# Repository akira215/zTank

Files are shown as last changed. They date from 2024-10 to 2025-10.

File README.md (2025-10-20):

# zTank
Tank survey, embedded sofware on dedicated PCB using ESP32C6 µC

# Description

This repository contain all the development for an electronic device that will monitor a water tank (such as rain collect tank) using zigbee to transmit data to a coordinator. It contains: 
 * A PCB design [PCB design](PCB/README.md)
 * An enclosure design to be printed in 3D [Enclosure design](3Dprint/README.md)
 * Source code of the embedded software on the board (in an ESP32C6 µC)
 * An External converter for Zigbee2MQTT service [external converter](external_converters)

# Principle

The board will collect data from various sensors surch as:
 * Upstream static pressure (pump side)
 * Downstream static pressure (home side) - difference between upstream and downstream static pressure is used to estimate filters clogging
 * Water level sensor, to estimate the available water volume in the tank
 * water pulse meter to count the consumption in the home
 * Additionally on board temperature sensor could be monitor

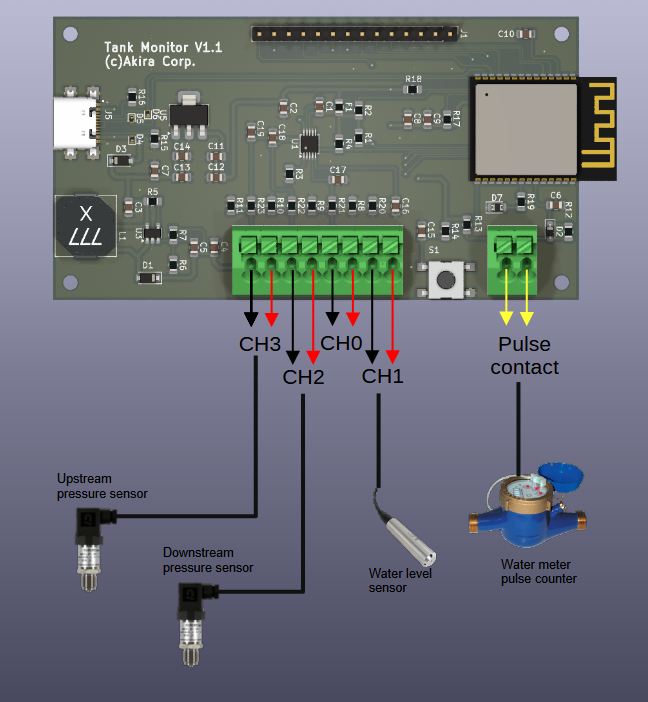
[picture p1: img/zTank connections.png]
zTank connections
 

 The 3 first sensors shall be 4-20mA sensor directly connected to the board. The water counter shall be a dry contact meter, connected to the board

 All these sensors have a calibration factor that can be updated directly form Zigbee2MQTT GUI. To avoid losing calibration, the device itself will keep updated theses factor in its Non Volatile Storage.

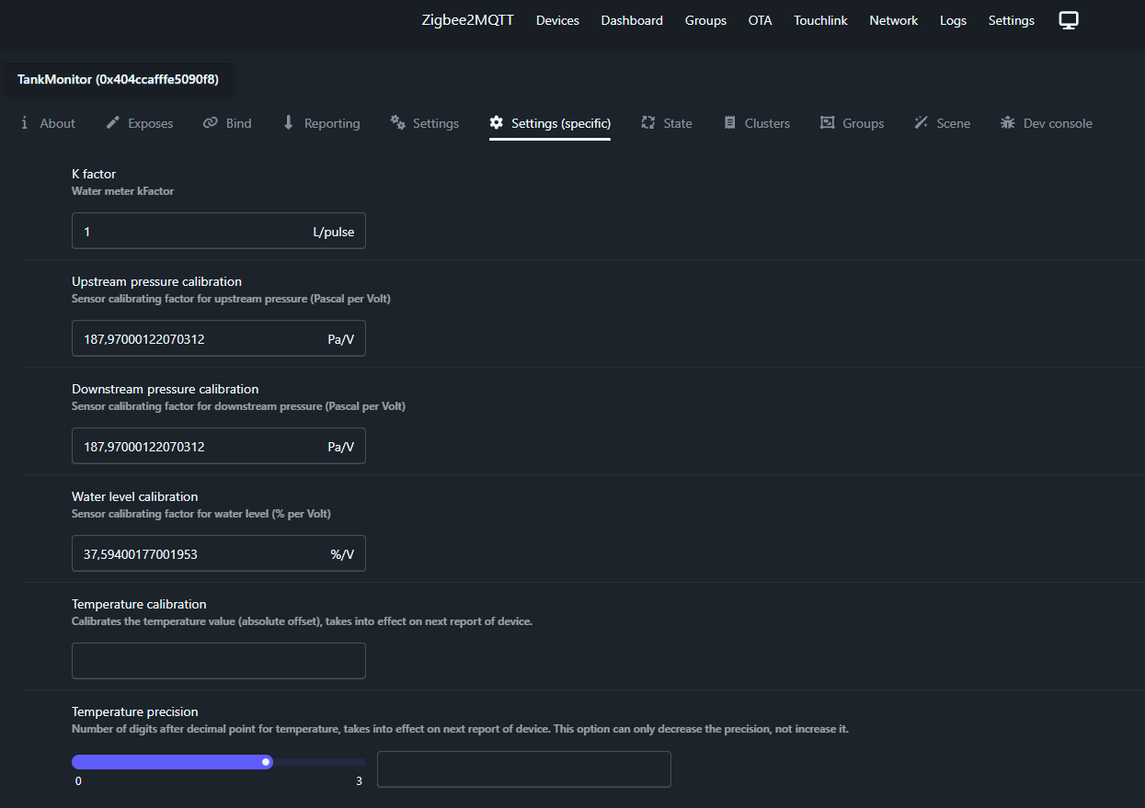
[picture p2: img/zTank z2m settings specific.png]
z2m settings (specific)


A 4-20mA input is available for any other futher sensor requirement. Adding a sensor will require to :
 * Update the embedded software
 * Update the external converter on Zigbee2MQTT side

## Usage

  * Short press button to join the zigbee network (coordinator shall grant pairing) -> LED shall flash, until network is joined, it then shutoff
  * Long press button to leave network. When the LED is fixed on, the device is not connected to the network neither is trying to join

## Sensor selection

### Upstream and downstream static pressure

  Regular pressure transmitter are not so expensive and efficient for that purpose. These 2 sensors shall have a measured range according to installation pressure. In regular network, pressure is limited to 3 bars, so selecting a sensor 0-5 bars seems a good choice. If the upper value is higher, the resolution of the measurement will be less as the ADC converter resolution is fixed.

  The shunt to convert current to tension for the ADC converter is 133R, and Imax for the sensor @max range will be 20mA so Umax for ADS1115 will be 2.66V (U=R*I). 5 bars = 500 kPa, so the calibration factor shall be 500 kPa / 2.66V = 187.97 kPa/V. Of course this factor shall be adjusted by measuring at the same location of one sensor the pressure, and correcting the reading of the sensor, but this short computation can help to start setting up calibration factor

### Water level

  Whatever technology of sensor could be used as soon as its output is 4-20mA current. Tests have been done using submerged differential pressure sensor, with the balance pipe to get the atmospheric pressure that run with the electrical cable, they worked properly. The range of this sensor shall be in accordance with the depth of the tank. The output value of Zigbee2MQTT will be a % of depth (meaning 100% when tank is full). Depending on the shape and cross section of the tank, this could be converted to a volume directly in the Z2M external converter, or outside Z2M in another software.

  The shunt to convert current to tension for the ADC converter is 133R, and Imax for the sensor @max range will be 20mA so Umax for ADS1115 will be 2.66V (U=R*I). For 100% the calibration factor shall be 100% / 2.66V = 37.594 %/V. 
  
  Of course this factor shall be adjusted when tank is full to read 100% in the Zigbee2MQTT output. For example, if yo have a 0-2m sensor and the require stroke of your tank (max height - min height before depriming pump) is 1.5m, it means that the 100% value of your tank will occur when sensor will read 1.5m (take care to install the sensor just before depriming pump). The voltage at the converter will be 1.5m/2m * 2.66V = 1.995V, so you will have to set the calibration factor considering 100% / 1.995V = 50.125%/V

### Water pulse counter

  The water meter shall send a pulse each XX L, whatever XX is. It is expected to have a dry contact that switch on and off each pulse. Hardware debouncer has been implemented for a particular counter, measuring bouncing using an oscilloscope. Computation of this RC filter has been provided here:
  [Spreadsheet](<PCB/2024-06-29 Comput.ods>)
    
  The kFactor to be set up in Zigbee2MQTT is only the L per pulse of the counter.

## Zigbee2MQTT integration

### External converter

External converter shall be loaded according to Zigbee2MQTT instructions:

[Zigbee2MQTT external converters](https://www.zigbee2mqtt.io/advanced/more/external_converters.html)

Restart Zigbee2MQTT `Webpage > Settings > Tools > Restart Zigbee2MQTT`

### Pairing zTank device

If the LED is fixed on, short press one time on the button, this will put the device in pairing mode.
Device is in Pairing Mode when the LED flahes quickly. 

Put Coordinator (or other device) in pairing mode using Zigbee2MQTT GUI (antenna symbol on the upper right of the screen with mention `All`)

After a short time, LED shall stop flashing. When LED is off, device is paired. You can check on Zigbee2MQTT device list

### Device icon

To add an icon in Zigbee2MQTT GUI, create a folder named `device_icon` in the root of Zigbee2MQTT docker installation (folder containing `configuration.yml`). In that foler, put the `zTank_icon.png` file contained in the `img` directory of this repository.

On Zigbee2MQTT GUI, go to `Devices` list and click on the device. Go to `Settings` tab and scroll down to the `icon` box.
Put `device_icons/zTank_icon.png` in that box. Icon shall be visible on Zigbee2MQTT GUI.

### Reporting

To develop*******************************************************************

## Build Instructions

The embedded software required `esp-ash-components`:

```
git submodule add https://github.com/akira215/esp-ash-components.git components
```

Create a partition.csv for zigbee and configure menuconfig with custom partition table (shall be done by default)

## Configuration

Configuration is available in `menuconfig` in the `Project setting` section:

### Pin Layout

  This section refer to hardware connection of LED button and volume meter. <span style="color:red">**These settings shall not be changed unless new hardware is developped.**</span>

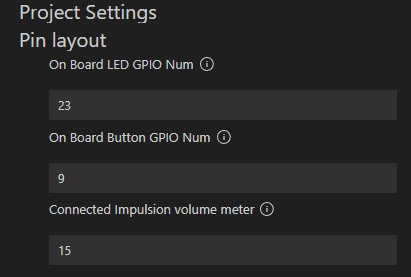
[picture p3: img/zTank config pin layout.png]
pin layout


### Zigbee endpoints

  This section refer to the endpoint for each sensor of the device. Any change in this number require to update the external converter accordingly

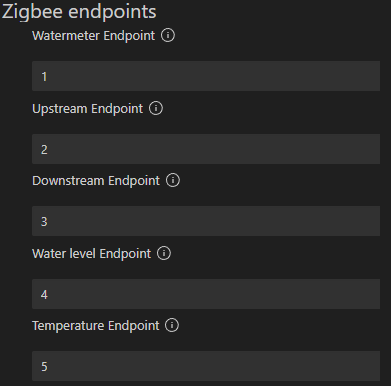
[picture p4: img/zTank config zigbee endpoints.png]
Zigbee endpoints


  And in Zigbee2MQTT external converter:

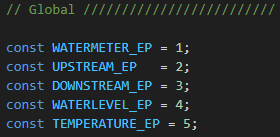
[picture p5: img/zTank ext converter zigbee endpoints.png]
External converter


### Zigbee device

  Zigbee stack has been sized doing extensive tests. <span style="color:red">**This setting shall not be changed.**</span>

Zigbee device

### ADS Pin Layout

  This section refer to hardware connection of ADS1115 converter to µC pin. <span style="color:red">**These settings shall not be changed unless new hardware is developped.**</span>

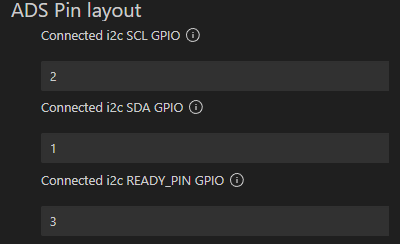
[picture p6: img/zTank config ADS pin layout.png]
ADS pin layout


### ADS Converter config

  The first 3 inputs refer to the channel in which each sensor is connected. Take care that channel are not implemented on the connector in a logical order, so please refer to pictures that describe which pins of the connector is connected to which ADC channel (and polarity for sensors)

  The delay between 2 queries of ADS is the update rate of the measurement. Between 2 measurement, ADS is put in sleep to optimize consumption. Take care that driver will trigger one conversion for each channel, so there is a minimal time between 2 queries, depending on the resolution set for the ADS.

  The delay between 2 queries of temperature is the update rate of the measurement of the internal µC temperature sensor.

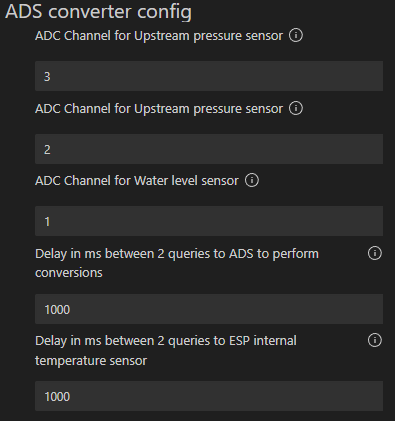
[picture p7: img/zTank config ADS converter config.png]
ADS converter config


## Current Status

Still work in progress, but is completely running. All bugs 
could be reported to try to improve it.

## PCB design

[PCB design](PCB/README.md)

## Enclosure design design

[Enclosure design](3Dprint/README.md)

## Caveats

### To be developped

OTA update

## Usage and Examples

## Changes

### New in version 0.0.0

## Credits

 * [Zigbee2MQTT](https://github.com/Koenkk/zigbee2mqtt)

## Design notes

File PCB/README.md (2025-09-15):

# zTank PCB
A dedicated PCB using ESP32C6 µC as been designed to optimize reliability and costs.

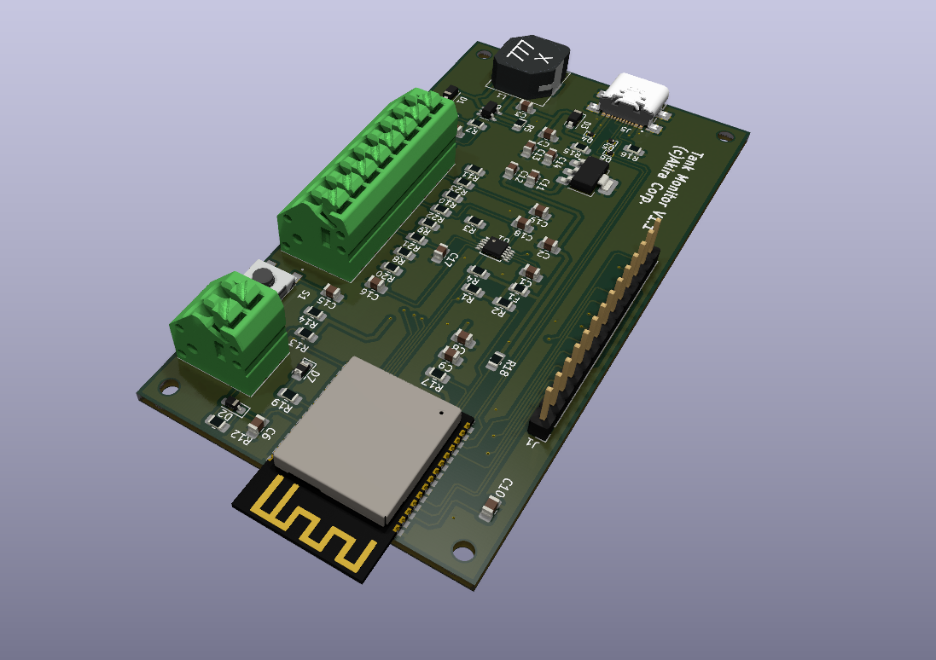
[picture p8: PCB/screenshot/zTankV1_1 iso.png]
Iso view of zTank PCB


## Tools

 The design of the PCB has been done with KiCad 9.0. Particular footprint and 3D STEP file are included in the `/footprints` folder for sake of maintenance

## Design

 The design is based on ESP32C6 WROOM with the following peripherials:
 * USB for power, flash device and output serial debug / info.
 * Powering circuit is done using MCP1826S 
 * A 4-20mA loop is built based on a LM2735X (1.6MHz) to raise voltage to about 20V
 * 4 channels 4-20mA sensors is provided and converted using ADS1115IDGS. It communicate with µC with i2c port
 * a debounced contact is provided for pulse counter
 * A push button is also provided for very simple HMI
 * PCB is also equipped by a LED for simpl HMI
 * Finally PCB is equipped with header that can be used for a touchscreen device in case of future needs (software lib already written and tested)

 Component size has been selected to 0805, except ESD protective diodes that are smaller.

### USB

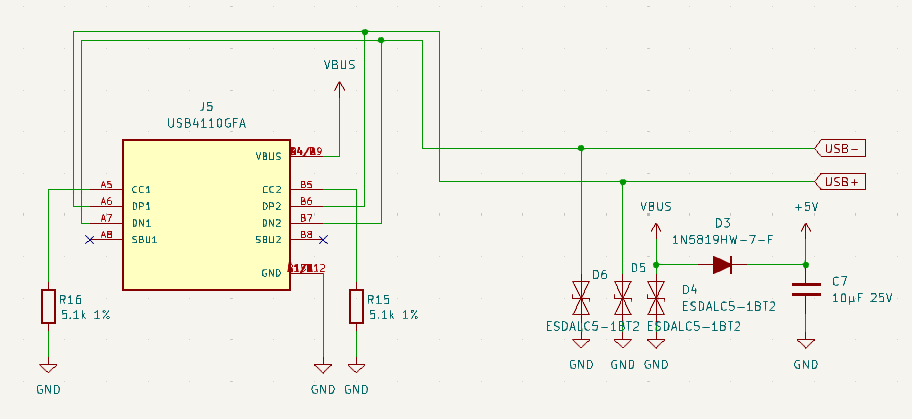
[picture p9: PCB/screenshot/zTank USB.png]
USB schematic
  

  USB socket is grounded to the main ground planes (2 sides).
  USB Lines `USB-` and `USB+` are directly connected to ESP32C6 to flash and monitor µC.
  `VBUS` is used to provide `+5V` (which is in fact lower than +5V) via a protective diode `D3`.

  All this 3 lines are protected by ESD protective diode.

### Voltage regulator

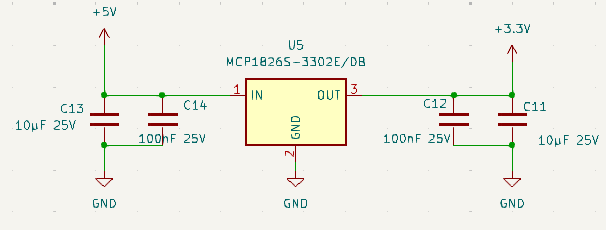
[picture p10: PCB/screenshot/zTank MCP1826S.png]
Regulator schematic
  

  All the board is powered using `+3.3V`. This voltage is provided by a fixed low-voltage regulator MCP1826S-3302E that can provide up to 1000mA.
  Fixed voltage regulator requires only few external component, in this case only capacitors are installed as per datasheet.

### 4-20mA Voltage circuit

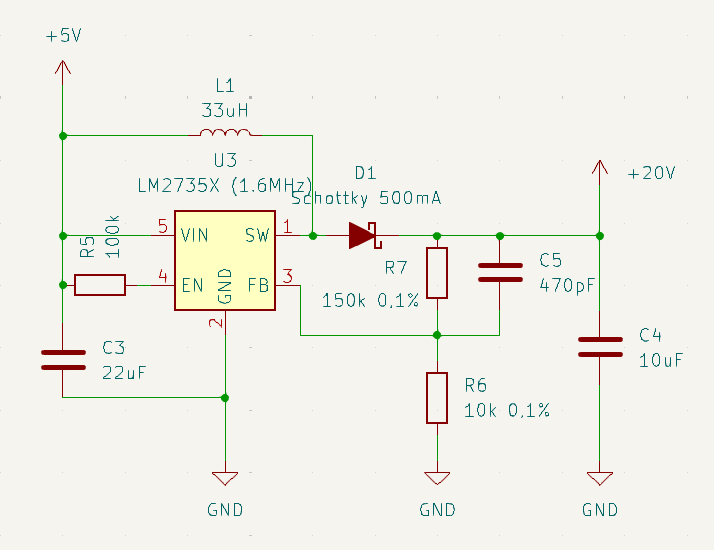
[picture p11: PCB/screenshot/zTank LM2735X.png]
LM2735X schematic
  

  To avoid noise on lines and due to voltage drop at each stage, 4-20mA loop voltage shall be at around 20V. Care shall be taken when changing this voltage as it may require adjustment (in the shunt values for instance) to avoid damaging other components.

  This voltage is produced from `+5V` using a boost type regulator LM2735X (@1.6MHz). Computation of the external components are provided in the LibreOffice Spreadsheet [PCB comput spreadsheet](<2024-06-29 Comput.ods>). A 33µH inductance has been selected to get a clean output voltage to avoid noise on sensors line.

### 4-20mA conversion

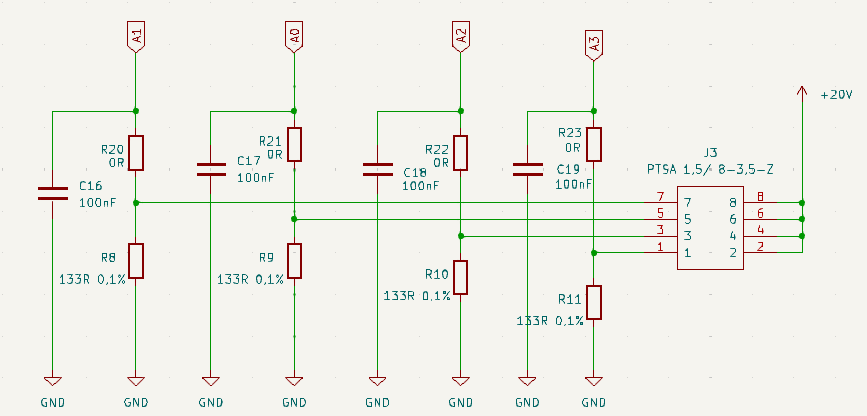
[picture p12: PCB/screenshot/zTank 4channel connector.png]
4 channel connector schematic
 

  4 channels are available via Phoenix contact 8 poles connector. Each channel input current is injected in a 133R shunt (low tolerance resistor) to output a voltage below 3.3V. A 100nF capacitor is provided to reduce noise.

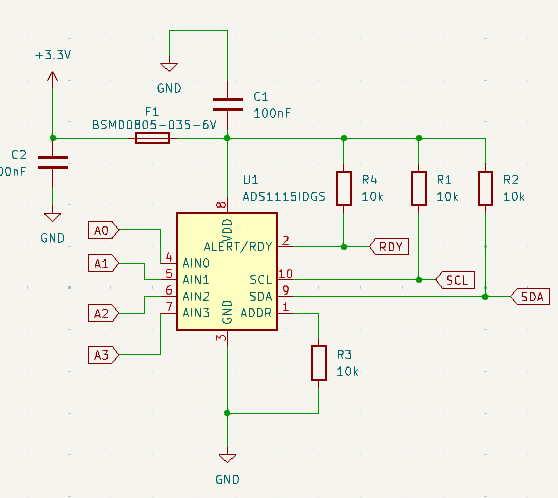
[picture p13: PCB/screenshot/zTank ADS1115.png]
ADS1115 schematic
  

  Each channel voltage is then converted in a digital signal using an ADS1115IDGS, that communicate with µC using i2c protocol. A ready pin is used to trigger an interrupt to the µC when data are available.
  External components are:
   * 10k resistor connected to the ground for the address of the device (only one on board so gnd is the common one)
   * 10k pull-up resistor on each signal (`SCL`, `SDA`, `RDY`) connected to µC
   * Decoupling capacitor for power lines and rearmable fuse to protect circuit

### Debounced contact

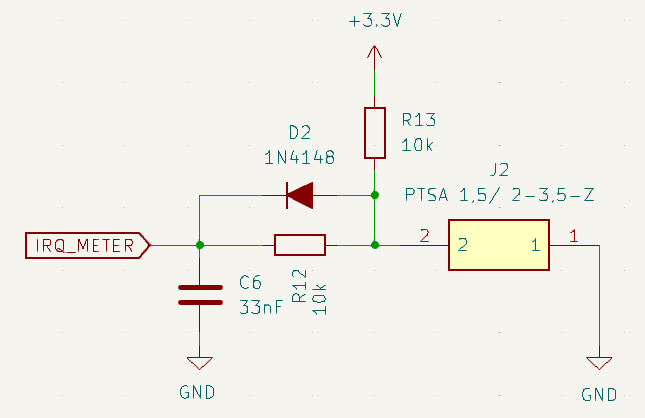
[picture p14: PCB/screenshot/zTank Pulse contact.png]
Debounced pulse schematic


An harware RC filter has been set up on this input to avoid false triggering. The computation of this filter is detailed in the spreadsheet file [PCB comput spreadsheet](<2024-06-29 Comput.ods>), bouncing duration has been measured using an oscilloscope in a unique water meter equiped with dry contact pulse output. It may be required to adjust this filter if the water meter seems to input false pulse to the µC. 

The only other component is a pull-up resistor to not let a float input.

### µC ESP32C6 WROOM

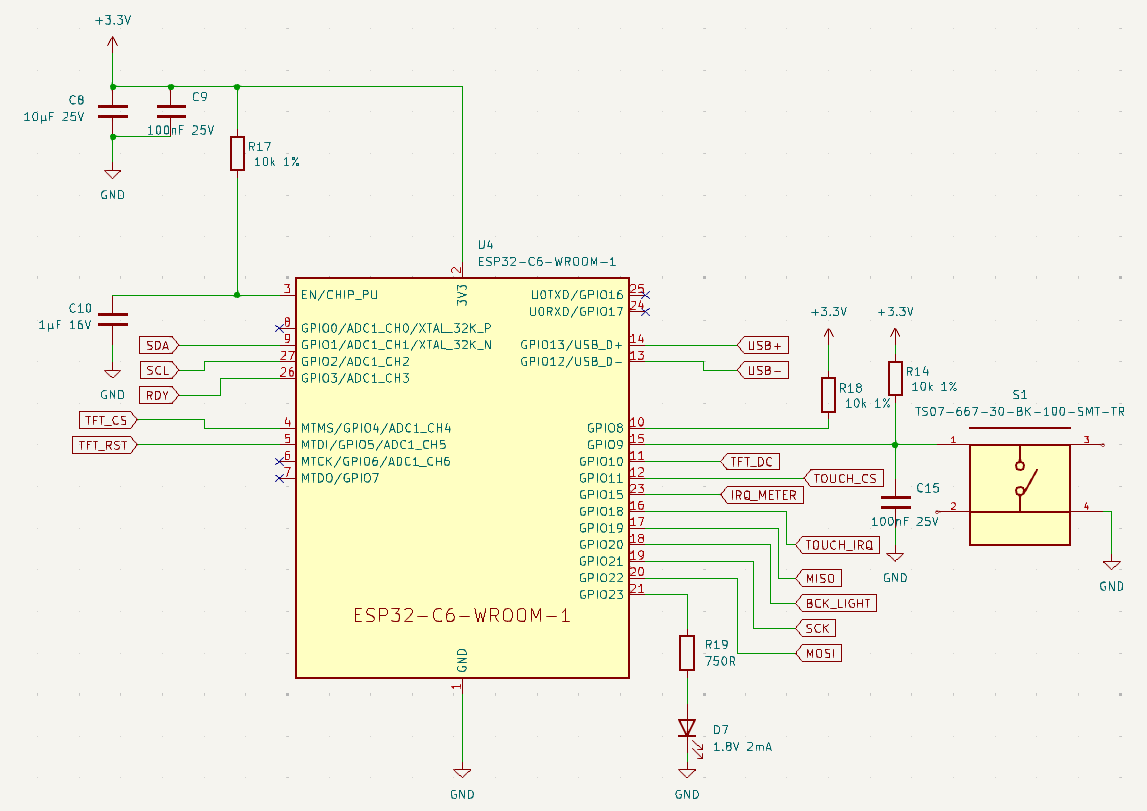
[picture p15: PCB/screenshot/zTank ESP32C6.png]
µC schematic


ESP32C6 power up is done using decoupling capacitor (10µF // 100nF).

The `EN` pin is driven to the `+3.3V` to enable the µC. 

`GPIO9` shall be pulled up to `+3.3V` to set the µC in normal execution mode (instead of ROM serial bootloader when `GPIO9` is pulled to the ground). Despite the doc says that it has an internal pull-up, µC will not boot normally after reporg if not driven to `+3.3V`.

`GPIO8` shall be driven to `+3.3V` as doc says, in order to enter the serial bootloader reliably.

### Push Button

Push button has been connected to `GPIO9`, so it can be used to boot/flash device by driving the pin low. Indeed, no operation is required on this button to flash µC using USB directly, and push button is used by software for HMI purpose.

### Led

A led is connected to `GPIO23` for HMI purpose as well. Resistor has been calculated according to LED spec to grant the required current.

### Header

A header is available to drive a touchscreen if required. It has not been integrated in the enclosure of this repo. It was planned and tested using a ILI9341 TFT touchscreen.

## PCB fabrication

Gerber files are included for fabrication. A batch of PCB has been produced by JLCPCB with the following configuration:

|Base Material |	FR-4	 | Layers |	2 |
|---|---|---|---|
|Dimension |	49 mm* 91 mm | PCB Qty |	20 |
|Product Type |	Industrial/Consumer electronics | Different Design |	1 |
|Delivery Format |	Single PCB	 | PCB Thickness |	1.6mm |
|Specify Stackup |	no	 | Layer Sequence | |	
|PCB Color |	Purple	 | Silkscreen |	White |
|Material Type |	TG135	 | Via Covering |	Tented |
|Surface Finish |	ENIG Gold Thickness: 1U"	 | Deburring/Edge rounding |	No |
|Outer Copper Weight  |	1 oz	 | Gold Fingers |	No |
|Electrical Test |	Flying Probe Fully Test	 | Castellated Holes |	no |
|Edge Plating |	No	 | Mark on PCB	 | Order Number |
|Blind Slot |	No	 | Min via hole size/diameter |	0.3mm/(0.4/0.45mm)|
|4-Wire Kelvin Test |	No	 | Paper between PCBs |	No |
|Appearance Quality |	IPC Class 2 Standard	 | Confirm Production file |	No |
|Silkscreen Technology|	Ink-jet/Screen Printing Silkscreen | Package Box |	With JLCPCB logo  |
|Inspection Report |	No	 | Board Outline Tolerance |	±0.2mm(Regular) |
|UL Marking |	No	 | Countersink Hole |	No |

## Assembly

A stencil as been produced by JLCPCB, so the assembly has been done using solder paste, manually placing components, and reflow is done using an hot plate.

The components that generate issues during that process are:
 * USB connector `J5` : often some bridges are created due to the high density of pin. It has to be manually fixed
 * ESD protection diodes `D4`, `D5` & `D6`: are they are really small and light, they moved during the reflow process. It has to be manually fixed with a soldering iron, as hot air gun make them move anyway whaterver the airflow is
 * Care should be taken on the pin of ADS converter `U1`(bridges) and µC `U4` (alke of solder)
 * Obviously connector `J1`, `J2` and `J3` have to be solded manually

## Usage

For routing simplicity, 4-20mA channels are not reparted logically on the board, please consider the scheme here below.

Debounced pulse contact don't have polarity.

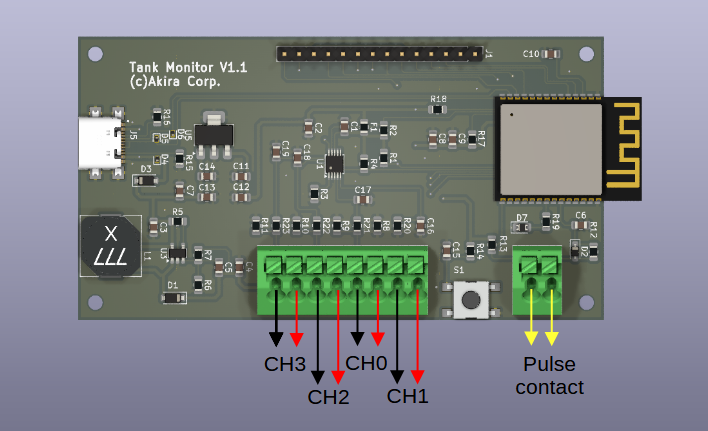
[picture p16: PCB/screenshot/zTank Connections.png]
Board connectors


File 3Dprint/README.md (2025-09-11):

# zTank Enclosure
The enclosure has been designed to fit and support the PCB.

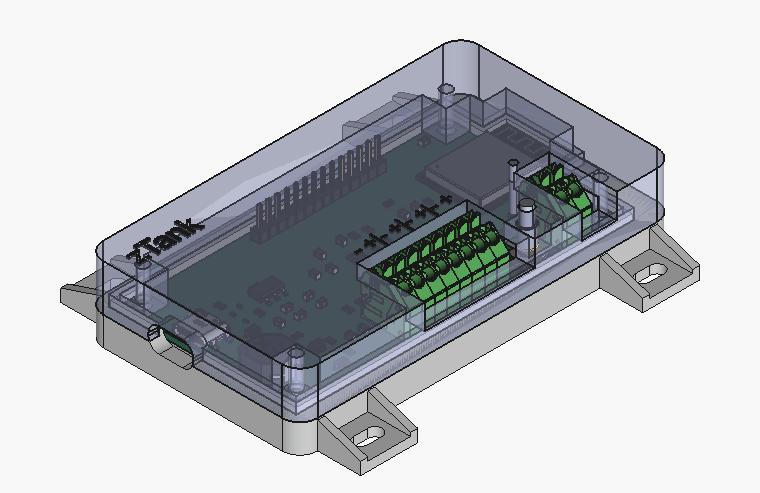
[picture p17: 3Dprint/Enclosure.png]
enclosure screenshot


## Tools

 The design of the enclosure has been made using FreeCad 1.0.2 with kicadStepUp Workbecnh addon (Tools -> AddOn Manager menu from FreeCad).

## Design

 zTank enclosure is composed by the following parts:
 - Bottom enclosure part which owns the padeyes to attach the device
 - Top enclosure which hold the button on the light guide.
 - Button that is an outside extension to press the PCB button easily
 - Light guide to show the LED light outside the box

 Except light guide, all parts are printed.

 The FreeCad files are provided in case of redesign is needed. The file contains a spreadsheet with the most important parameters, as the bodies are build based on parametrical design from this spreadsheet.

 Also a LibreOffice Calc file is provided to justify the inserts holes

## 3D printers parameters

 Using a Creality K1C with all standard parameters for Hyper PLA 0.16mmm (with 0.4mm nozzle) requires only 2 changes:
 - Walls number to 3 or 4
 - Infill density of 50% with AI infill to save some PLA

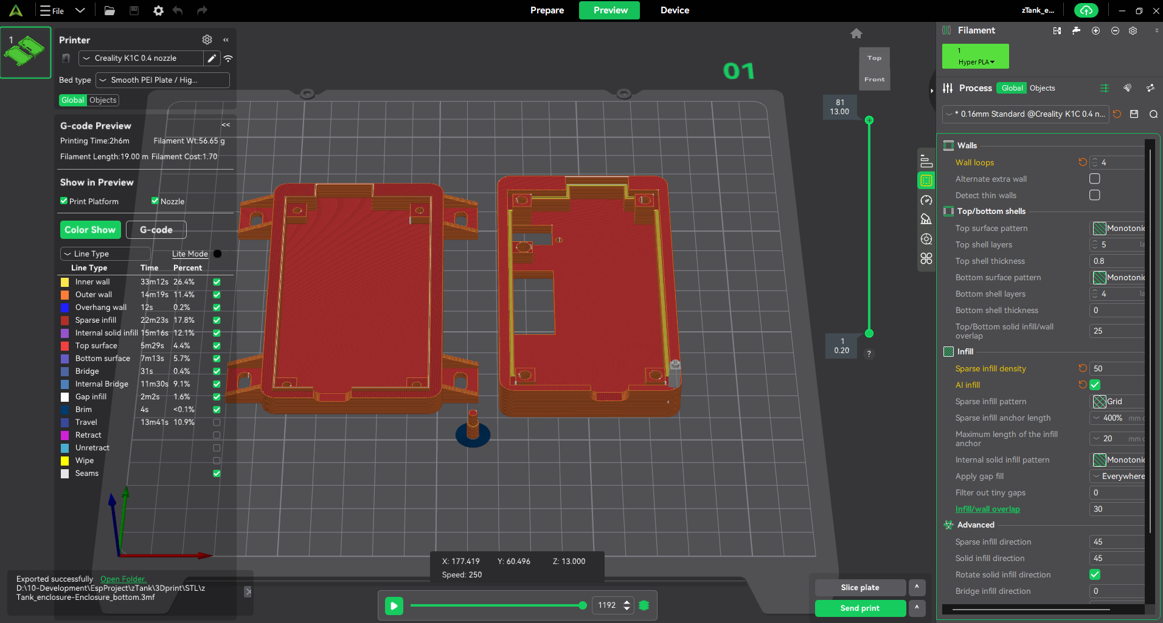
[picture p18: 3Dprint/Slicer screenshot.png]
Creality slicer screenshot
 

 The button is printed vertically, as the top enclosure is rotated 180° so that the plane surface is on the base plate. Bottom body is laid as it is.
 Take care to print the button slowly between layer otherwise it will deform during printing.

## Mounting

 For closing the enclosure, 4 inserts M2 x 6mm x 3.5mm are required to be installed in the Top Enclosure part. It should be installed using a dedicated tips, using temperature surch as:
 - for PLA this is around 225 °C, 
 - for PETG 245 °C, 
 - for ABS 265 °C

 4 screws of M2 x 16mm are required to close the box.

 The lighting guide from the LED is done using a 1.75mm translucent filament, glued in the hole in front of the LED. It shall be cut as close as possible to the DEL to correctly transmit the light (you could install it with the PCB installed inside the box, push it up to the LED and then cut is from outside, sand it properly and then glue it).

 Button is simply inserted in the top enclosure prior to close the box, it will be locked thanks to the shoulder on the cylinder, its length may be adjusted to fit perfectly the tolerance of the assembly.

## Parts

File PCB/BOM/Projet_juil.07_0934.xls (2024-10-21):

TANK_MONITOR
N° Mouser | N° de fab. | Fabricant | N° client | Description | RoHS | Cycle de vie | Qté. | Prix (EUR) | Ext. : (EUR)
511-ESDALC5-1BT2 | ESDALC5-1BT2 | STMicroelectronics |  | ESD Protection Diodes / TVS Diodes Single Line Transil Vbr 5V min 26pF 0 | RoHS : conforme |  | 3 | 0,288 € | 0,86 €
579-MCP1826S-3302EDB | MCP1826S-3302E/DB | Microchip |  | Régulateurs de tension LDO 1A CMOS LDO Vout 3.3V ETR | RoHS : conforme |  | 1 | 0,846 € | 0,85 €
179-TS0766730BK100SM | TS07-667-30-BK-100-SMT-TR | CUI Devices |  | Interrupteurs de contact 6 x 6.7 mm, 3 mm Act Height, 100 gf, Black, Surface Mount, TR, SPST, | RoHS : conforme |  | 1 | 0,205 € | 0,21 €
356-ESP32C6WROOM1N8 | ESP32-C6-WROOM-1-N8 | Espressif |  | Modules multiprotocoles ESP32-C6-WROOM-1 is a ESP32-C6 based module, which supports Wi-Fi 6 in 2.4 GHz band, Bluetooth 5, Zigbee 3.0 and Thread. If's pin-to-pin compatible with the ESP34-WROOM series module. With low power consumption, it is an ideal choice for a variety of | RoHS : conforme | Nouveau produit | 1 | 2,91 € | 2,91 €
994-MSS1048-333MLC | MSS1048-333MLC | Coilcraft |  | Inductances de puissance - CMS 33uH Shld 20% 2.8A 66mOhms | RoHS : conforme |  | 1 | 2,58 € | 2,58 €
651-1985250 | 1985250 | Phoenix Contact |  | Borniers fixes PTSA 1.5/8-3.5-Z | RoHS : conforme |  | 1 | 1,19 € | 1,19 €
651-1985195 | 1985195 | Phoenix Contact |  | Borniers fixes PTSA 1.5/2-3.5-Z | RoHS : conforme |  | 1 | 0,372 € | 0,37 €
595-ADS1115IDGSR | ADS1115IDGSR | Texas Instruments |  | Convertisseurs analogique-numérique - CAN 16B ADC w/ Int MUX PGA Comp Osc & Ref | RoHS : conforme |  | 1 | 4,39 € | 4,39 €
640-USB4110-GF-A | USB4110-GF-A | Global Connector Technology (GCT) |  | Connecteurs USB USB Type C, 2.0, Rec, SMT , G/F, RA , Top Mnt, T & R | RoHS : conforme |  | 1 | 1,30 € | 1,30 €
667-ERA-6AEB1330V | ERA-6AEB1330V | Panasonic |  | Résistances à couches minces - CMS 0805 133ohm 0.1% 25ppm | Conforme à RoHS par dispense |  | 4 | 0,121 € | 0,48 €
604-APT2012LSECKJ3RV | APT2012LSECK/J3-PRV | Kingbright |  | DEL standard - CMS 2.0X1.2MM LOW CRNT | RoHS : conforme |  | 1 | 0,577 € | 0,58 €
667-ERA-6AED751V | ERA-6AED751V | Panasonic |  | Résistances à couches minces - CMS 0805 750ohms 25ppm 0.5% AEC-Q200 | Conforme à RoHS par dispense |  | 1 | 0,177 € | 0,18 €
667-ERA-6AED103V | ERA-6AED103V | Panasonic |  | Résistances à couches minces - CMS 0805 10Kohms 25ppm 0.5% AEC-Q200 | Conforme à RoHS par dispense |  | 10 | 0,128 € | 1,28 €
71-CRCW0805-0-E3 | CRCW08050000Z0EA | Vishay |  | Résistances à couches épaisses - CMS 1/8watt ZEROohm Jumper | Conforme à RoHS par dispense |  | 4 | 0,093 € | 0,37 €
755-SFR10EZPF5101 | SFR10EZPF5101 | ROHM Semiconductor |  | Résistances à couches épaisses - CMS 5.1Kohm 0805 1% |  |  | 2 | 0,158 € | 0,32 €
667-ERA-6AEB1823V | ERA-6AEB1823V | Panasonic |  | Résistances à couches minces - CMS 0805 182Kohm 0.1% 25ppm | Conforme à RoHS par dispense |  | 1 | 0,121 € | 0,12 €
667-ERJ-UP6D1003V | ERJ-UP6D1003V | Panasonic |  | Résistances à couches épaisses - CMS 0805 Anti-sulfur 0.5W, 0.5%, 100KOhm AEC-Q200 | RoHS : conforme | Nouveau produit | 1 | 0,288 € | 0,29 €
530-0ZCK0035FF2G | 0ZCK0035FF2G | Bel |  | Fusibles réarmables - PPTC | RoHS : conforme |  | 1 | 0,177 € | 0,18 €
80-C0805C104K5R | C0805C104K5RACTU | KEMET |  | Condensateurs céramique multicouches MLCC - CMS 50V 0.1uF X7R 0805 10% | RoHS : conforme |  | 10 | 0,061 € | 0,61 €
80-C0805C105K4R | C0805C105K4RACTU | KEMET |  | Condensateurs céramique multicouches MLCC - CMS 16V 1uF X7R 0805 10% | RoHS : conforme |  | 1 | 0,093 € | 0,09 €
80-C0805C106K3P | C0805C106K3PACTU | KEMET |  | Condensateurs céramique multicouches MLCC - CMS 25V 10uF X5R 0805 10% | RoHS : conforme |  | 5 | 0,233 € | 1,17 €
80-C0805C226M9P7800 | C0805C226M9PAC7800 | KEMET |  | Condensateurs céramique multicouches MLCC - CMS 6.3V 22uF X5R 0805 20% | RoHS : conforme |  | 1 | 0,195 € | 0,20 €
80-C0805X471K5R | C0805X471K5RACTU | KEMET |  | Condensateurs céramique multicouches MLCC - CMS 50V 470pF X7R 0805 10% | RoHS : conforme |  | 1 | 0,298 € | 0,30 €
80-C0805C333K3GECTU | C0805C333K3GECTU | KEMET |  | Condensateurs céramique multicouches MLCC - CMS 25V 0.033uF C0G 0805 10% | RoHS : conforme |  | 1 | 0,27 € | 0,27 €
841-PMEG3005EGWX | PMEG3005EGWX | Nexperia |  | Diodes et redresseurs Schottky PMEG3005EGW/SOD123/SOD2 | RoHS : conforme |  | 1 | 0,279 € | 0,28 €
512-1N4148WS | 1N4148WS | onsemi |  | Diodes de commutation de signal faible Small Signal Diode | RoHS : conforme |  | 1 | 0,177 € | 0,18 €
621-1N5819HW-F | 1N5819HW-7-F | Diodes Incorporated |  | Diodes et redresseurs Schottky Vr/40V Io/1A T/R | RoHS : conforme |  | 1 | 0,326 € | 0,33 €
926-LM2735XMF/NOPB | LM2735XMF/NOPB | Texas Instruments |  | Régulateurs de tension de commutation SPACE-EFF BOOST AND SEPIC DC-DC REG | RoHS : conforme |  | 1 | 2,66 € | 2,66 €

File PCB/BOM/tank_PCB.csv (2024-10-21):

Id | Référence | Empreinte | Quantité | Désignation | Fournisseur et réf
1 | R11,R10,R8,R9 | R_0805_2012Metric_Pad1.20x1.40mm_HandSolder | 4 | 133R 0,1%
2 | R19 | R_0805_2012Metric_Pad1.20x1.40mm_HandSolder | 1 | 60R
3 | C10 | C_0805_2012Metric_Pad1.18x1.45mm_HandSolder | 1 | 1µF 16V
4 | C12,C9,C14,C15 | C_0805_2012Metric_Pad1.18x1.45mm_HandSolder | 4 | 100nF 25V
5 | C16,C1,C17,C19,C18,C2 | C_0805_2012Metric_Pad1.18x1.45mm_HandSolder | 6 | 100nF
6 | C5 | C_0805_2012Metric_Pad1.18x1.45mm_HandSolder | 1 | 470pF
7 | D6,D5,D4 | D_SOD-882D | 3 | ESDALC5-1BT2
8 | R13,R4,R1,R3,R12,R2 | R_0805_2012Metric_Pad1.20x1.40mm_HandSolder | 6 | 10k
9 | R22,R20,R21,R23 | R_0805_2012Metric_Pad1.20x1.40mm_HandSolder | 4 | 0R
10 | R7 | R_0805_2012Metric_Pad1.20x1.40mm_HandSolder | 1 | 182k 0,1%
11 | L1 | L_10.4x10.4_H4.8 | 1 | 33uH
12 | D1 | D_SOD-123 | 1 | Schottky 500mA
13 | R15,R16 | R_0805_2012Metric_Pad1.20x1.40mm_HandSolder | 2 | 5.1k 1%
14 | U1 | TSSOP-10_3x3mm_P0.5mm | 1 | ADS1115IDGS
15 | J2 | 1985195 | 1 | PTSA 1,5/ 2-3,5-Z
16 | D2 | D_SOD-323_HandSoldering | 1 | 1N4148
17 | R17,R18 | R_0805_2012Metric_Pad1.20x1.40mm_HandSolder | 2 | 10k 1%
18 | U3 | SOT-23-5 | 1 | LM2735X (1.6MHz)
19 | S1 | SW_TS07-667-30-BK-100-SMT-TR | 1 | TS07-667-30-BK-100-SMT-TR
20 | F1 | Fuse_0805_2012Metric | 1 | BSMD0805-035-6V
21 | C3 | C_0805_2012Metric_Pad1.18x1.45mm_HandSolder | 1 | 22uF
22 | C13,C11,C7,C8 | C_0805_2012Metric_Pad1.18x1.45mm_HandSolder | 4 | 10µF 25V
23 | C6 | C_0805_2012Metric_Pad1.18x1.45mm_HandSolder | 1 | 33nF
24 | C4 | C_0805_2012Metric_Pad1.18x1.45mm_HandSolder | 1 | 10uF
25 | D3 | D_SOD-123 | 1 | 1N5819HW-7-F
26 | J5 | GCT_USB4110GFA | 1 | USB4110GFA
27 | U4 | ESP32-C6-WROOM-1 | 1 | ESP32-C6-WROOM-1
28 | J3 | 1985250 | 1 | PTSA 1,5/ 8-3,5-Z
29 | J1 | PinHeader_1x14_P2.54mm_Vertical | 1 | TFT
30 | D7 | D_0805_2012Metric_Pad1.15x1.40mm_HandSolder | 1 | 2.1V 20mA
31 | R5 | R_0805_2012Metric_Pad1.20x1.40mm_HandSolder | 1 | 100k
32 | R6 | R_0805_2012Metric_Pad1.20x1.40mm_HandSolder | 1 | 10k 0,1%
33 | U5 | SOT-223-3_TabPin2 | 1 | MCP1826S-3302E/DB

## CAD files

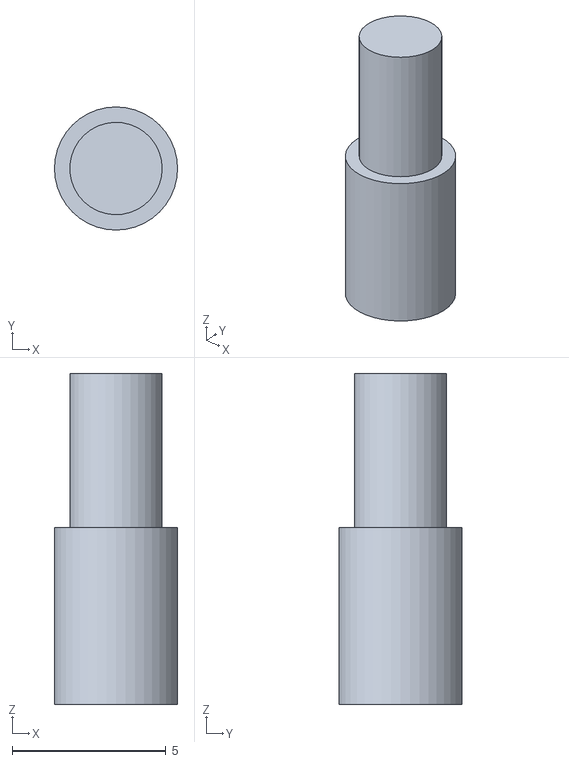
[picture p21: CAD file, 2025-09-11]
3Dprint/STL/zTank_enclosure-Button.stl
4.00 x 4.00 x 10.8

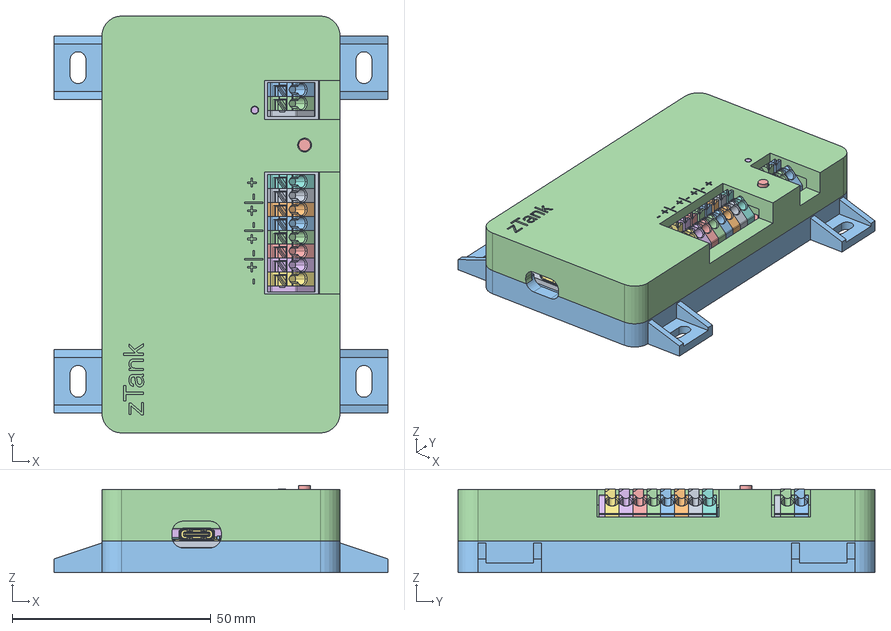
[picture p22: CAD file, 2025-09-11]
3Dprint/zTank_enclosure.FCStd
84.0 x 105.0 x 22.0 mm
Pcb_5180
R11_R_0805_2012Metric_8d3d2f9dee65 x 23
C10_C_0805_2012Metric_aadd674c95c2 x 19
D6_D_SOD-882D_3e8a34a7d1fc x 3
L1_Coilcraft-MSS1048_bed8f5a73708
D1_D_SOD-123_a1590cb893a3 x 2
U1_TSSOP-10_3x3mm_P0.5mm_120f7ab93f95
D2_D_SOD-323_f12dec0a8d24
U3_SOT-23-5_78e00c41a4e3
CUI_DEVICES_TS07-667-30-BK-100-SMT-TR
CUI_DEVICES_TS07-667-30-BK-100-SMT-TR001
CUI_DEVICES_TS07-667-30-BK-100-SMT-TR002
CUI_DEVICES_TS07-667-30-BK-100-SMT-TR003
CUI_DEVICES_TS07-667-30-BK-100-SMT-TR004
CUI_DEVICES_TS07-667-30-BK-100-SMT-TR005
CUI_DEVICES_TS07-667-30-BK-100-SMT-TR006
F1_Fuse_0805_2012Metric_303ee67611bb
USB4110-GF-A_revB(1) MF
uid__2428
MINI-ANT-TYPEB.STEP
R0201_20210301.xtd
R0201_20210301.xtd001
R0201_20210301.xtd002
ESP32-C6_QFN40_5X5_202306.xtd
ESP32-C6_QFN40_5X5_202306.xtd001
XTAL3225_20210301.xtd
XTAL3225_20210301.xtd001
XTAL3225_20210301.xtd002
XTAL3225_20210301.xtd003
XTAL3225_20210301.xtd004
SOP8_rev1_20210308.xtd
R0201_20210301.xtd004
R0201_20210301.xtd005
R0201_20210301.xtd006
R0201_20210301.xtd008
R0201_20210301.xtd009
R0201_20210301.xtd010
R0201_20210301.xtd012
R0201_20210301.xtd013
R0201_20210301.xtd014
R0201_20210301.xtd016
R0201_20210301.xtd017
R0201_20210301.xtd018
R0201_20210301.xtd020
R0201_20210301.xtd021
R0201_20210301.xtd022
R0201_20210301.xtd024
R0201_20210301.xtd025
R0201_20210301.xtd026
R0201_20210301.xtd028
R0201_20210301.xtd029
R0201_20210301.xtd030
R0201_20210301.xtd032
R0201_20210301.xtd033
R0201_20210301.xtd034
L0201_20210301.xtd
L0201_20210301.xtd001
DFN1006.xtd
C0402_20210301.xtd
C0201_20210301.xtd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

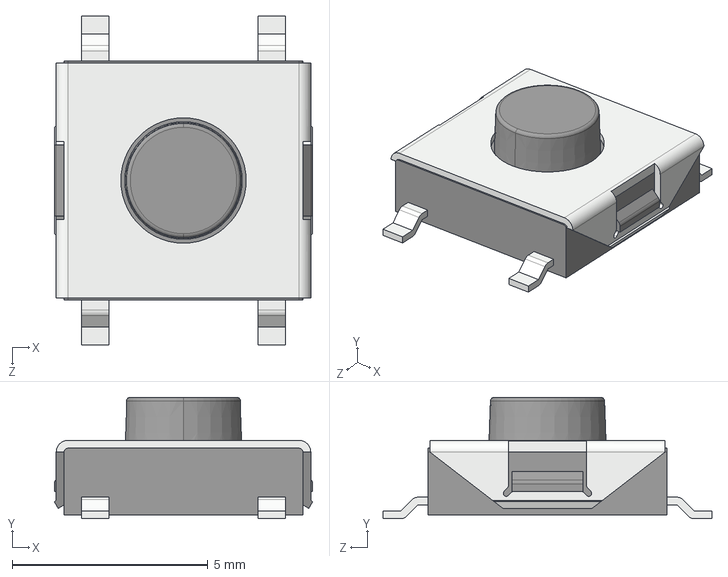
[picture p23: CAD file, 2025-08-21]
PCB/footprints/3D/CUI_DEVICES_TS07-667-30-BK-100-SMT-TR.step
6.60 x 3.10 x 8.40 mm

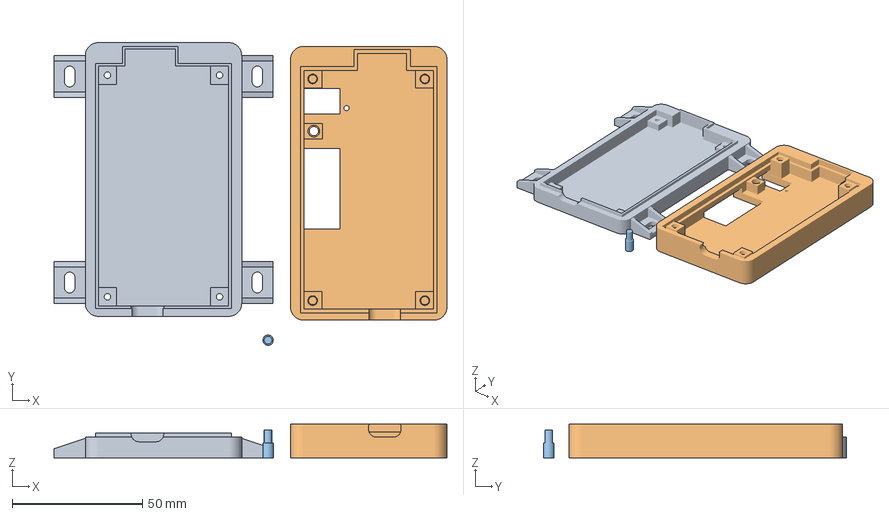
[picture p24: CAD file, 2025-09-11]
3Dprint/STL/zTank_enclosure-Enclosure_bottom.3mf
150.7 x 116.1 x 13.0 mm
zTank_enclosure-Enclosure_bottom.stl
zTank_enclosure-Enclosure_Top.stl
zTank_enclosure-Button.stl

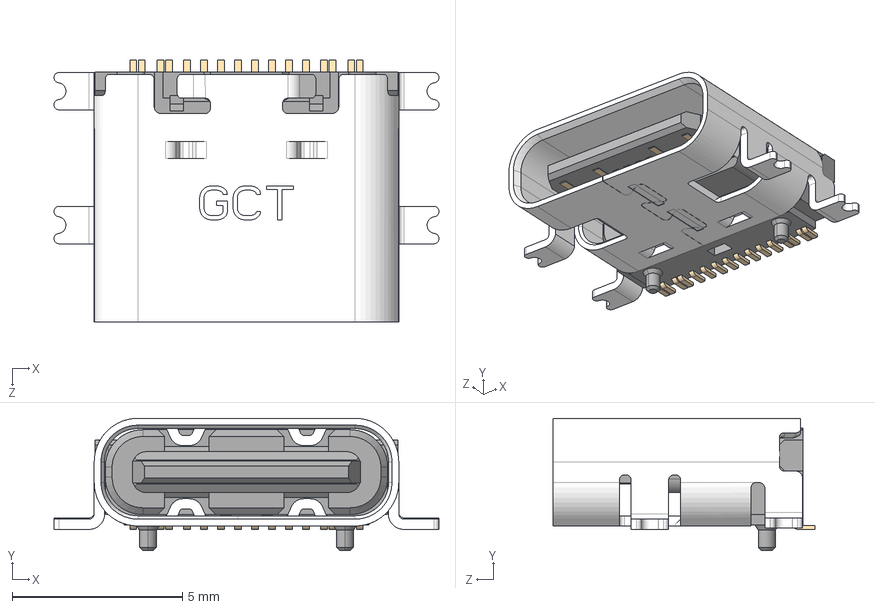
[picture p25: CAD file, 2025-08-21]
PCB/footprints/3D/USB4110GFA.step
11.3 x 3.89 x 7.70 mm

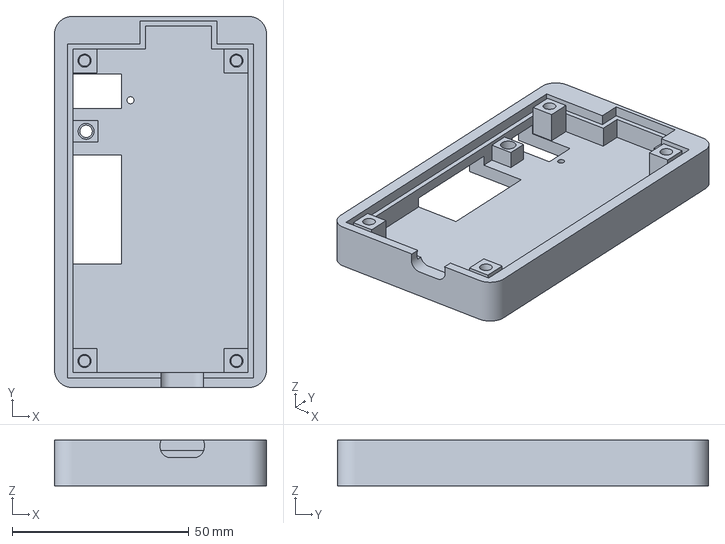
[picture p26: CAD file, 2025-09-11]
3Dprint/STL/zTank_enclosure-Enclosure_Top.3mf
60.0 x 105.0 x 13.0 mm

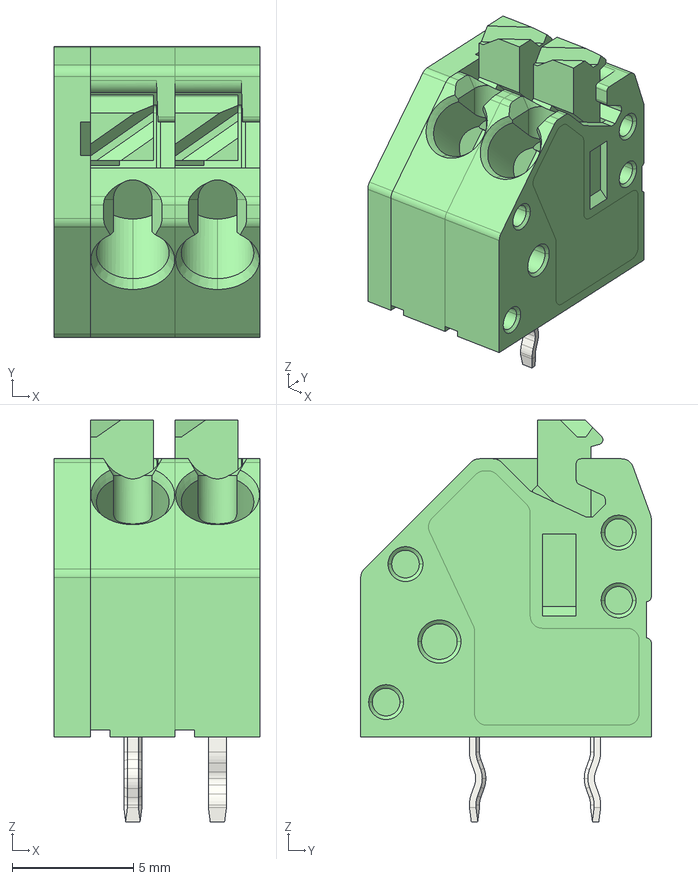
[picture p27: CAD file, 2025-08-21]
PCB/footprints/3D/pxc_1985195_05_PTSA-1-5-2-3-5-Z_3D.stp
8.50 x 12.0 x 16.6 mm

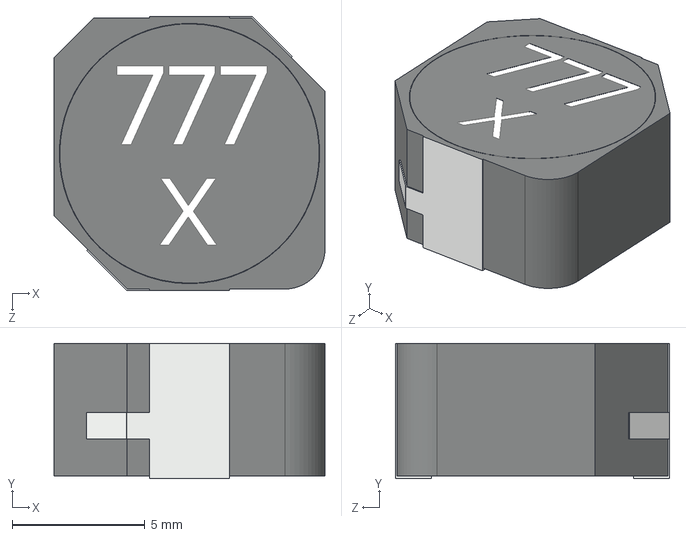
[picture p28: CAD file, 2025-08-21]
PCB/footprints/3D/Coilcraft-MSS1048.STEP
10.2 x 5.10 x 10.3 mm

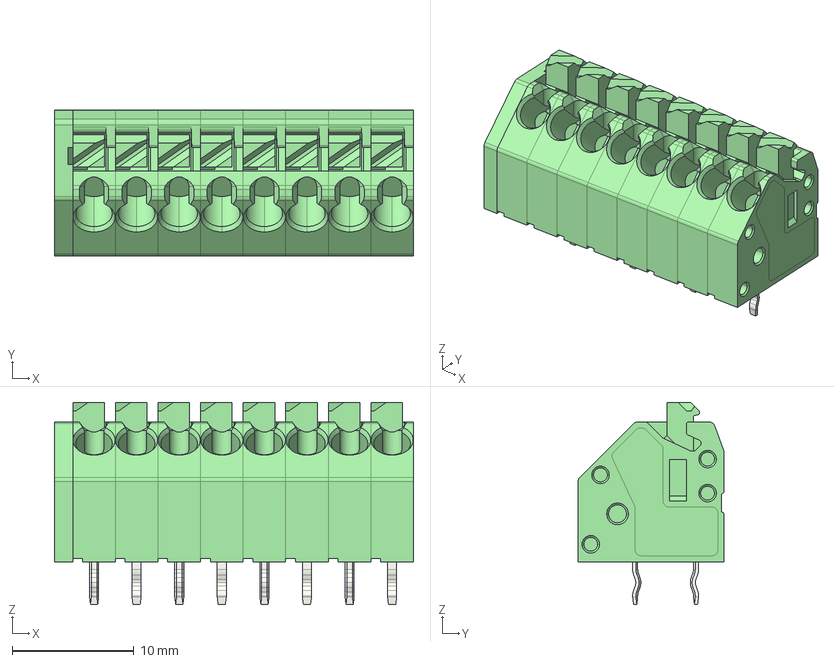
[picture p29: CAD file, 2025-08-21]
PCB/footprints/3D/1985250.stp
29.5 x 12.0 x 16.6 mm

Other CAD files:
3Dprint/STL/zTank_enclosure-Enclosure_Top.stl
3Dprint/STL/zTank_enclosure-Enclosure_bottom.stl

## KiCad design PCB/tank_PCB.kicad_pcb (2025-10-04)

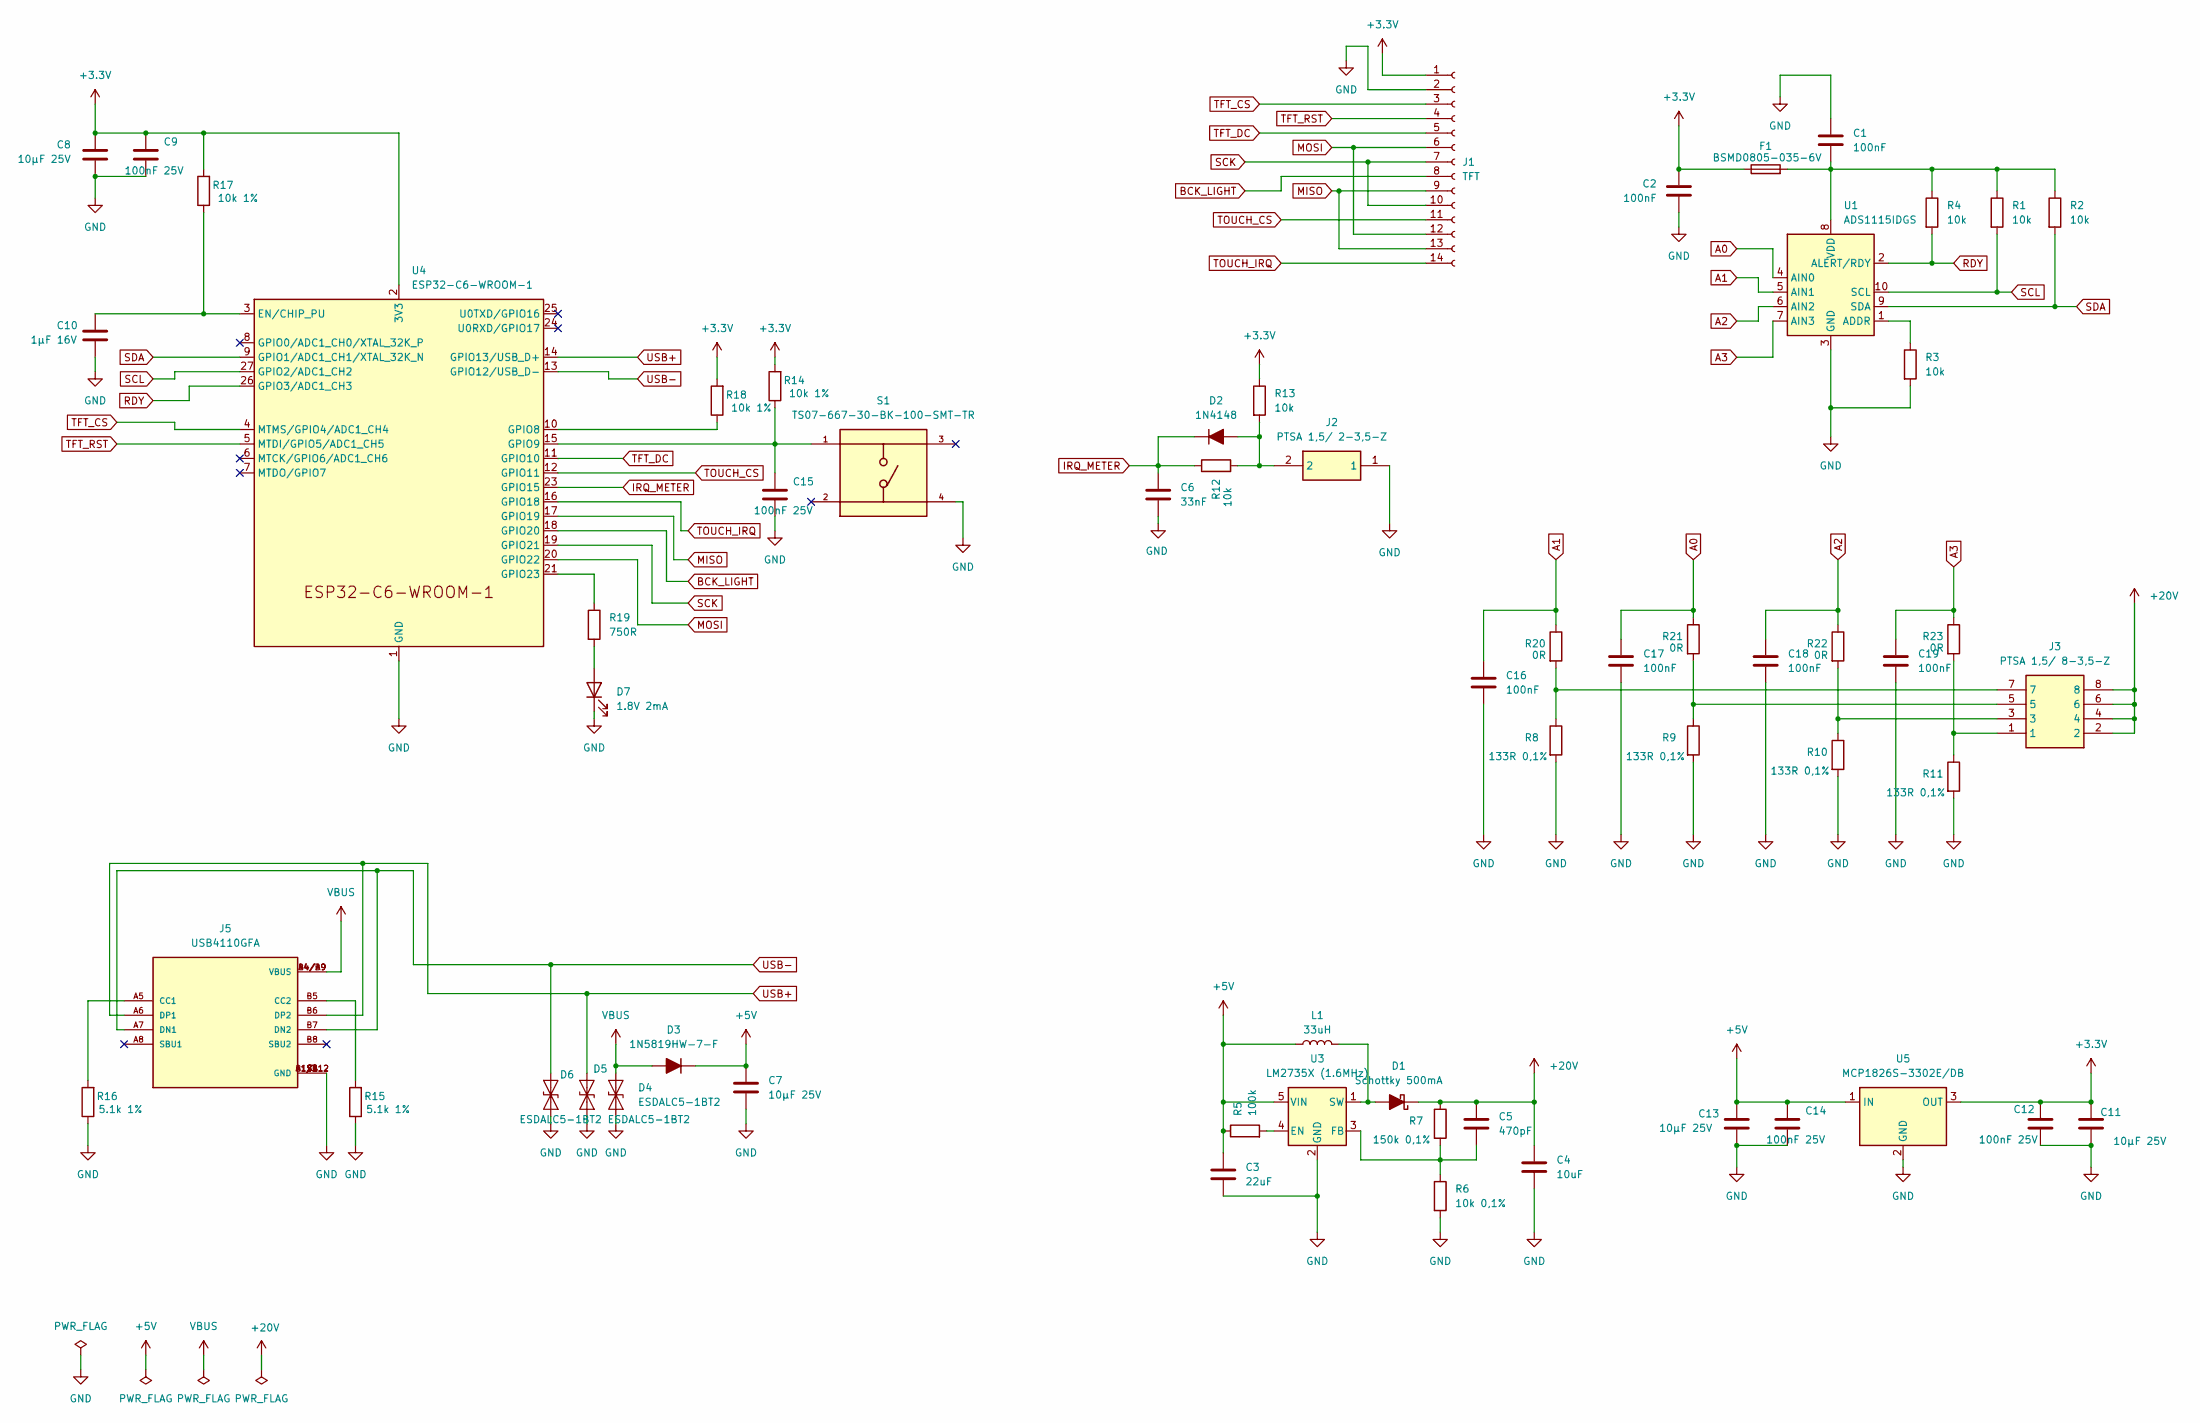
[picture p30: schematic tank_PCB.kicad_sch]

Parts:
C1, C2, C16, C17, C18, C19: 100nF; C_0805_2012Metric_Pad1.18x1.45mm_HandSolder
C3: 22uF; C_0805_2012Metric_Pad1.18x1.45mm_HandSolder
C4: 10uF; C_0805_2012Metric_Pad1.18x1.45mm_HandSolder
C5: 470pF; C_0805_2012Metric_Pad1.18x1.45mm_HandSolder
C6: 33nF; C_0805_2012Metric_Pad1.18x1.45mm_HandSolder
C7, C8, C11, C13: 10µF 25V; C_0805_2012Metric_Pad1.18x1.45mm_HandSolder
C9, C12, C14, C15: 100nF 25V; C_0805_2012Metric_Pad1.18x1.45mm_HandSolder
C10: 1µF 16V; C_0805_2012Metric_Pad1.18x1.45mm_HandSolder
D1: Schottky 500mA; D_SOD-123
D2: 1N4148; D_SOD-323_HandSoldering
D3: 1N5819HW-7-F; D_SOD-123
D4, D5, D6: ESDALC5-1BT2; D_SOD-882D
D7: 1.8V 2mA; D_0805_2012Metric_Pad1.15x1.40mm_HandSolder
F1: BSMD0805-035-6V; Fuse_0805_2012Metric
J1: TFT; PinHeader_1x14_P2.54mm_Vertical
J2: PTSA 1,5/ 2-3,5-Z; Phoenix Contact PTSA 2; Manufacturer_Part_Number 1985195; Mouser Part Number 651-1985195
J3: PTSA 1,5/ 8-3,5-Z; Phoenix Contact PTSA 8; Manufacturer_Part_Number 1985250; Mouser Part Number 651-1985250
J5: USB4110GFA; GCT_USB4110GFA
L1: 33uH; L_10.4x10.4_H4.8
R1, R2, R3, R4, R12, R13: 10k; R_0805_2012Metric_Pad1.20x1.40mm_HandSolder
R5: 100k; R_0805_2012Metric_Pad1.20x1.40mm_HandSolder
R6: 10k 0,1%; R_0805_2012Metric_Pad1.20x1.40mm_HandSolder
R7: 150k 0,1%; R_0805_2012Metric_Pad1.20x1.40mm_HandSolder
R8, R9, R10, R11: 133R 0,1%; R_0805_2012Metric_Pad1.20x1.40mm_HandSolder
R14, R17, R18: 10k 1%; R_0805_2012Metric_Pad1.20x1.40mm_HandSolder
R15, R16: 5.1k 1%; R_0805_2012Metric_Pad1.20x1.40mm_HandSolder
R19: 750R; R_0805_2012Metric_Pad1.20x1.40mm_HandSolder
R20, R21, R22, R23: 0R; R_0805_2012Metric_Pad1.20x1.40mm_HandSolder
S1: TS07-667-30-BK-100-SMT-TR; CUI switch SW_TS07-667-30-BK-100-SMT-TR; PARTREV 1.0
U1: ADS1115IDGS; TSSOP-10_3x3mm_P0.5mm
U3: LM2735X (1.6MHz); SOT-23-5
U4: ESP32-C6-WROOM-1
U5: MCP1826S-3302E/DB; SOT-223-3_TabPin2

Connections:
+3.3V: C2.1, C8.1, C9.1, C11.1, C12.1, F1.1, J1.1, R13.1, R14.2, R17.2, R18.2, U4.2 (3V3), U5.3 (OUT)
+5V: C3.1, C7.1, C13.1, C14.1, D3.1 (K), L1.1, R5.1, U3.5 (VIN), U5.1 (IN)
+20V: C4.1, C5.1, D1.1 (K), J3.2, J3.4, J3.6, J3.8, R7.1
A0: C17.1, R21.1, U1.4 (AIN0)
A1: C16.1, R20.1, U1.5 (AIN1)
A2: C18.1, R22.1, U1.6 (AIN2)
A3: C19.1, R23.1, U1.7 (AIN3)
BCK_LIGHT: J1.8, U4.18 (GPIO20)
GND: C1.1, C2.2, C3.2, C4.2, C6.2, C7.2, C8.2, C9.2, C10.2, C11.2, C12.2, C13.2, C14.2, C15.2, C16.2, C17.2, C18.2, C19.2, D4.1 (A1), D5.1 (A1), D6.1 (A1), D7.1 (K), J1.2, J2.1, J5.A1/B12 (GND), J5.B1/A12 (GND), J5.S1 (GND), J5.S2 (GND), J5.S3 (GND), J5.S4 (GND), R3.2, R6.2, R8.2, R9.2, R10.2, R11.2, R15.1, R16.1, S1.4, U1.3 (GND), U3.2 (GND), U4.1 (GND), U4.28 (GND), U4.29 (GND), U5.2 (GND)
IRQ_METER: C6.1, D2.1 (K), R12.1, U4.23 (GPIO15)
MISO: J1.9, J1.13, U4.17 (GPIO19)
MOSI: J1.6, J1.12, U4.20 (GPIO22)
unnamed: D1.2 (A), L1.2, U3.1 (SW)
unnamed: D2.2 (A), J2.2, R12.2, R13.2
unnamed: D7.2 (A), R19.2
unnamed: J3.1, R11.1, R23.2
unnamed: J3.3, R10.1, R22.2
unnamed: J3.5, R9.1, R21.2
unnamed: J3.7, R8.1, R20.2
unnamed: J5.A5 (CC1), R16.2
unnamed: J5.B5 (CC2), R15.2
unnamed: R3.1, U1.1 (ADDR)
unnamed: C1.2, F1.2, R1.1, R2.1, R4.1, U1.8 (VDD)
unnamed: R5.2, U3.4 (EN)
unnamed: C5.2, R6.1, R7.2, U3.3 (FB)
unnamed: C10.1, R17.1, U4.3 (EN/CHIP_PU)
unnamed: R18.1, U4.10 (GPIO8)
unnamed: C15.1, R14.1, S1.1, U4.15 (GPIO9)
unnamed: R19.1, U4.21 (GPIO23)
RDY: R4.2, U1.2 (ALERT/RDY), U4.26 (GPIO3/ADC1_CH3)
SCK: J1.7, J1.10, U4.19 (GPIO21)
SCL: R1.2, U1.10 (SCL), U4.27 (GPIO2/ADC1_CH2)
SDA: R2.2, U1.9 (SDA), U4.9 (GPIO1/ADC1_CH1/XTAL_32K_N)
TFT_CS: J1.3, U4.4 (MTMS/GPIO4/ADC1_CH4)
TFT_DC: J1.5, U4.11 (GPIO10)
TFT_RST: J1.4, U4.5 (MTDI/GPIO5/ADC1_CH5)
TOUCH_CS: J1.11, U4.12 (GPIO11)
TOUCH_IRQ: J1.14, U4.16 (GPIO18)
USB+: D5.2 (A2), J5.A6 (DP1), J5.B6 (DP2), U4.14 (GPIO13/USB_D+)
USB-: D6.2 (A2), J5.A7 (DN1), J5.B7 (DN2), U4.13 (GPIO12/USB_D-)
VBUS: D3.2 (A), D4.2 (A2), J5.A4/B9 (VBUS), J5.B4/A9 (VBUS)

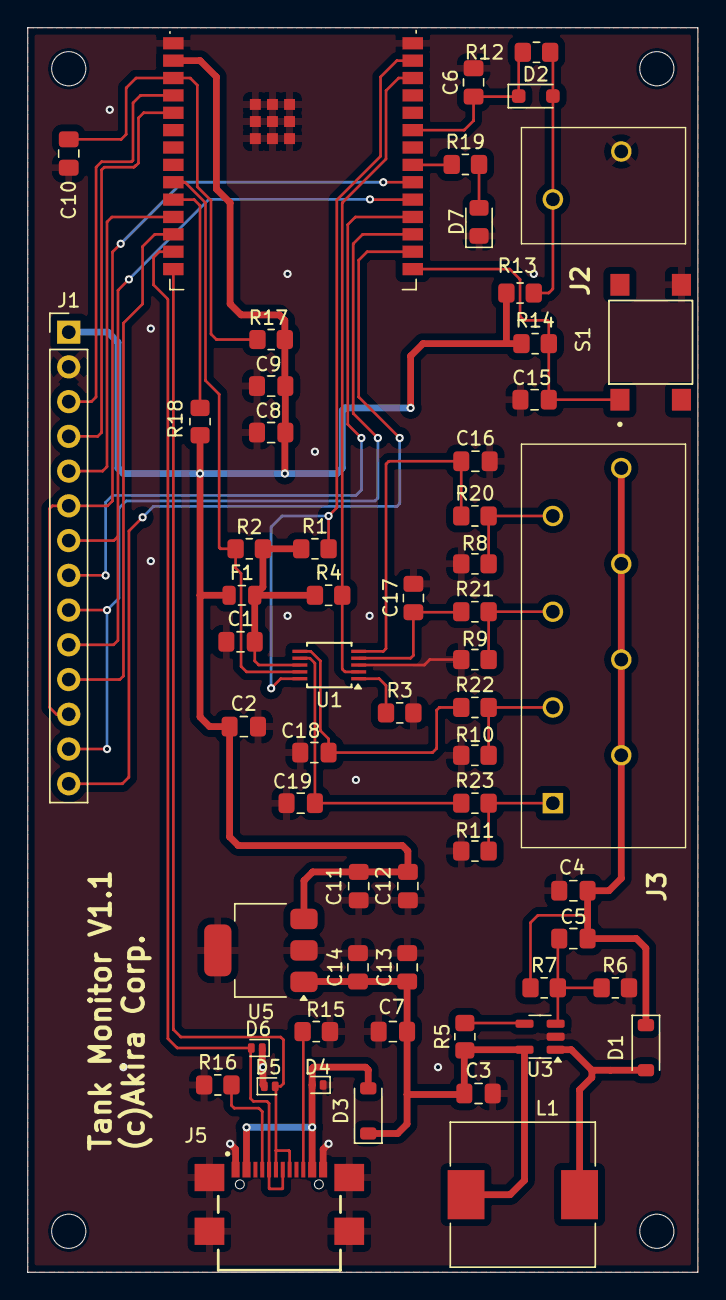
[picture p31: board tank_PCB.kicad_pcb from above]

Board: 2 copper layers, 49.0 x 91.0 mm, 60 parts (0 on the bottom side), 41 nets.

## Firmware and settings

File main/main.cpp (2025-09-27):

//#define LOG_LOCAL_LEVEL ESP_LOG_VERBOSE

#include "main.h"

#include <freertos/FreeRTOS.h>
#include <freertos/task.h>
#include <esp_log.h>
#include <functional>

#include <iostream>

#include <vector> // todel

#include "zbEndpoint.h" // to del
#include "periodicSoftTask.h" // to del

/*
#include "zbBasicCluster.h" //TODEL
#include "zbPowerCfgCluster.h"
#include "zbIdentifyCluster.h"
#include "zbTemperatureMeasCluster.h"
*/

#include "esp_check.h" // todel

// to del
#define ESP_TEMP_SENSOR_UPDATE_INTERVAL (1)     /* Local sensor update interval (second) */
#define ESP_TEMP_SENSOR_MIN_VALUE       (-10)   /* Local sensor min measured value (degree Celsius) */
#define ESP_TEMP_SENSOR_MAX_VALUE       (80)    /* Local sensor max measured value (degree Celsius) */


static const char *TAG = "Main_app";
BlinkTask* Main::_ledBlinking = nullptr;
GpioOutput Main::_led { (gpio_num_t)CONFIG_PIN_LED }; //TODO led pin number in config file

Main App;

Main::Main()
{
    // Setting the log level for each module
    esp_log_level_set("Main_app", ESP_LOG_DEBUG);  // Put verbose to check available stack
    esp_log_level_set("ZbNode", ESP_LOG_DEBUG); 
    esp_log_level_set("ZbEndpoint", ESP_LOG_VERBOSE);
    esp_log_level_set("ZbNode", ESP_LOG_VERBOSE);
    esp_log_level_set("AdsDriver", ESP_LOG_INFO);
    esp_log_level_set("TempDriver", ESP_LOG_VERBOSE);
    esp_log_level_set("ZbCluster", ESP_LOG_VERBOSE);
    esp_log_level_set("EventLoop", ESP_LOG_DEBUG);
    esp_log_level_set("PersistedValue", ESP_LOG_VERBOSE); 
}

// static
void Main::ledFlash(uint64_t speed)
{
    if(speed == 0) 
    {
        if(_ledBlinking){
        delete _ledBlinking;
        _ledBlinking = nullptr;
        }
        _led.off();
    } else if(speed == -1) {
        if(_ledBlinking){
        delete _ledBlinking;
        _ledBlinking = nullptr;
        }
        _led.on();
    } else {
        if(!_ledBlinking)
            _ledBlinking = new BlinkTask(_led, speed); // very short flash
        else
            _ledBlinking->setBlinkPeriod(speed);
    }

}

//Static
void Main::shortPressHandler(void *handler_args, esp_event_base_t base, int32_t id, void *event_data)
{
    ESP_LOGV(TAG,"Short Press detected %ld -",id);
    if(ZbNode::getInstance()->isJoined())  
    {
        ESP_LOGI(TAG,"Short Press detected but device is join to zigbee network, nothing to do");
    } else {
         ZbNode::getInstance()->joinNetwork();
    }
}

//Static
void Main::longPressHandler(void *handler_args, esp_event_base_t base, int32_t id, void *event_data)
{

    ESP_LOGV(TAG,"Long Press detected %ld -",id);
    ZbNode::getInstance()->leaveNetwork();

}

// Static
void Main::identifyHandler(uint16_t attrId, void* value)
{
    if(attrId != ESP_ZB_ZCL_ATTR_IDENTIFY_IDENTIFY_TIME_ID)
        return;
    
    ESP_LOGI(TAG,"Identifying time %d",*((uint16_t*)value));
    if (*((uint16_t*)value) !=0)
        ledFlash(50);
    else
        ledFlash(0);
}

//void Main::zbDeviceEventHandler(ZbNode::nodeEvent_t event)
void Main::zbDeviceEventHandler(ZbNode::nodeEvent_t event)
{
    switch(event){
        case ZbNode::JOINED:
            // Device just joined the network
            {
            ledFlash(0);
            // Synchronise RTC clock of the device
            _timeClient->syncRTC();

            _checkRTCSync = new PeriodicSoftTask(&Main::checkRTCSync, this, 500);

            // Wait for the clock to be synchronized (retry every seconds)
            //while(!(_timeClient->isSynchronized()))
            //    vTaskDelay( 1000 / portTICK_PERIOD_MS );
           
            //if (_fMeter) {
            //    ESP_LOGW(TAG,"Clock is finally sync!");
            //}
                

            }
            break;
        case ZbNode::JOINING:
            ledFlash(FAST_BLINK);
            break;
        case ZbNode::NLME_STATUS:
            if(_zbDevice->isJoined()) 
                ledFlash(0);
            else 
                ledFlash(50); //very short flash
            break;
        case ZbNode::LEAVING:
            ledFlash(50);
            break;
        case ZbNode::LEFT:
            ledFlash(-1);
            break; 
        default:
            ESP_LOGW(TAG,"Device Event Handler, event %d not registered occured", 
                        static_cast<uint>(event));
            break;
    }
  
}

void Main::checkRTCSync(){
    if(_timeClient->isSynchronized()){
        if (_fMeter) {
            ESP_LOGV(TAG,"Clock is sync - triggering action on RTC");
            _fMeter->setupResetTask(CONFIG_SEC_FROM_MIDNIGHT);
        }

        delete _checkRTCSync;
        _checkRTCSync = nullptr;
    }
}

void Main::setup(void)
{
    ESP_LOGI(TAG,"---------- Setup ----------");

    _button.enablePullup();
    _buttonTask = new ButtonTask (_button);
    _buttonTask->setShortPressHandler(&shortPressHandler);
    _buttonTask->setLongPressHandler(&longPressHandler,(void*)this);

    AdsDriver::getInstance().setup();


    ESP_LOGI(TAG,"Creating Zigbee device");
    _zbDevice = ZbNode::getInstance();
    _zbDevice->registerNodeEventHandler(&Main::zbDeviceEventHandler, this);

    // Endpoints Construct ////////////////////////////////////////////////
    ZbEndPoint* measEp = new ZbEndPoint(CONFIG_WATERMETER_EP, 
                            ESP_ZB_HA_METER_INTERFACE_DEVICE_ID);
    
    ZbEndPoint* upstreamEp = new ZbEndPoint(CONFIG_UPSTREAM_EP, 
                            ESP_ZB_HA_SIMPLE_SENSOR_DEVICE_ID);

    ZbEndPoint* downstreamEp = new ZbEndPoint(CONFIG_DOWNSTREAM_EP, 
                            ESP_ZB_HA_SIMPLE_SENSOR_DEVICE_ID);
    
    ZbEndPoint* waterLevelEp = new ZbEndPoint(CONFIG_WATER_LEVEL_EP, 
                            ESP_ZB_HA_SIMPLE_SENSOR_DEVICE_ID);
    
    ZbEndPoint* tempEp = new ZbEndPoint(CONFIG_TEMPERATURE_EP, 
                            ESP_ZB_HA_TEMPERATURE_SENSOR_DEVICE_ID);

    
    // Clusters Construct ////////////////////////////////////////////////
    ZbBasicCluster* basicCl = new ZbBasicCluster(false,
                        ESP_ZB_ZCL_BASIC_ZCL_VERSION_DEFAULT_VALUE,
                        (uint8_t)0x01);
    basicCl->addAttribute(ESP_ZB_ZCL_ATTR_BASIC_MANUFACTURER_NAME_ID,
                        (void*)MANUFACTURER_NAME);
    basicCl->addAttribute(ESP_ZB_ZCL_ATTR_BASIC_MODEL_IDENTIFIER_ID,
                        (void*)MODEL_IDENTIFIER);


    _otaCluster = new ZbOtaClusterClient(CONFIG_OTA_TIMER_QUERY,
                                        CONFIG_HARDWARE_VERSION,
                                        CONFIG_MAX_DATA_SIZE);
    
/*
    ZbPowerCfgCluster* powerCl = new ZbPowerCfgCluster(false,
                                    2400, 25);
*/

    // Sensor clusters
    _fMeter = new WaterFlowMeasCluster();

    // Upstream channel 2
    _upstreamPressure = new WaterPressureMeasCluster(CONFIG_UPSTREAM_PRESSURE_CH);
    
    // Downstream channel 3
    _downstreamPressure = new WaterPressureMeasCluster(CONFIG_DOWNSTREAM_PRESSURE_CH);
    
    // WaterLevel channel 4
    _waterLevel = new WaterLevelMeasCluster(CONFIG_WATER_LEVEL_CH);
    
    // Temperature cluster
    /*
    _tempMeasurement  = new ZbTemperatureMeasCluster(false,
                                ESP_TEMP_SENSOR_MIN_VALUE,
                                ESP_TEMP_SENSOR_MAX_VALUE,
                                ESP_ZB_ZCL_TEMP_MEASUREMENT_MEASURED_VALUE_DEFAULT);
    */
    _tempMeasurement = new TempCluster();

    _timeClient = new ZbTimeClusterClient();

    ESP_LOGI(TAG,"---------------- Register ------------------------");
    
    ZbIdentifyCluster* identifyServer = new ZbIdentifyCluster();
    ZbIdentifyCluster* identifyClient = new ZbIdentifyCluster(true);
    ZbIdentifyCluster* identifyServer2 = new ZbIdentifyCluster(*identifyServer);
    ZbIdentifyCluster* identifyServer3 = new ZbIdentifyCluster(*identifyServer);
    ZbIdentifyCluster* identifyServer4 = new ZbIdentifyCluster(*identifyServer);
    ZbIdentifyCluster* identifyServer5 = new ZbIdentifyCluster(*identifyServer);
    
    // Attaching Clusters  ////////////////////////////////////////////////
    measEp->addCluster(identifyServer);
    measEp->addCluster(basicCl);
    measEp->addCluster(_fMeter);
    measEp->addCluster(_fMeter->getKfactorCluster());
    measEp->addCluster(_otaCluster);

    upstreamEp->addCluster(identifyServer2);
    upstreamEp->addCluster(_upstreamPressure);
    upstreamEp->addCluster(_upstreamPressure->getKfactorCluster());

    downstreamEp->addCluster(identifyServer3);
    downstreamEp->addCluster(_downstreamPressure);
    downstreamEp->addCluster(_downstreamPressure->getKfactorCluster());

    waterLevelEp->addCluster(identifyServer4);
    waterLevelEp->addCluster(_waterLevel);
    waterLevelEp->addCluster(_waterLevel->getKfactorCluster());
    
    tempEp->addCluster(identifyServer5);
    tempEp->addCluster(identifyClient);
    tempEp->addCluster(_tempMeasurement);
    tempEp->addCluster(_timeClient);

    // Attaching Enpoints  ////////////////////////////////////////////////
    _zbDevice->addEndPoint(*measEp);
    _zbDevice->addEndPoint(*upstreamEp);
    _zbDevice->addEndPoint(*downstreamEp);
    _zbDevice->addEndPoint(*waterLevelEp);
    _zbDevice->addEndPoint(*tempEp);
    
    
    // Get task handles from tasks names
    _eventLoopHandle = xTaskGetHandle( "ZbEventLoop" );
    _xButtonHandle = xTaskGetHandle( "button_task" ); 
    
    //driver_init();

    ESP_LOGI(TAG,"---------------- Starting ZbDevice ------------------------");
    //_zbDevice->setReadyCallback(initWhenJoined);
    
    //ZbApsData* inst = ZbApsData::getInstance();
    _zbDevice->start();

    vTaskDelay(pdMS_TO_TICKS(7000));

    // Start AdsDriver after zigbee stack as it will start to change attributes
    // 1000ms for each measures
    AdsDriver::getInstance().start(CONFIG_DELAY_ADS_DRIVER);

    _tempMeasurement->start(CONFIG_DELAY_TEMPERATURE_DRIVER);

}



void Main::run(void)
{
    
    ESP_LOGV(TAG,"Main task high water mark %d", 
                            uxTaskGetStackHighWaterMark(NULL));

    ESP_LOGV(TAG,"Event Loop task high water mark %d", 
                            uxTaskGetStackHighWaterMark(_eventLoopHandle));
    
    ESP_LOGV(TAG,"Button task high water mark %d", uxTaskGetStackHighWaterMark(_xButtonHandle));
    ESP_LOGV(TAG,"Zigbee task high water mark %d", 
                            uxTaskGetStackHighWaterMark(_zbDevice->getZbTask()));


    vTaskDelay(pdMS_TO_TICKS(2000));

    //ESP_LOGD(TAG,"App is running");
    
}


extern "C" void app_main(void)
{
    App.setup();

    while (true)
    {
        App.run();
    }    

    //should not reach here
}

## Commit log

2024-09-23 Working Stack
    [partitions.csv]
2024-10-01 testing flowmeter
2024-10-21 adding PCB
    [2024-06-29 Comput.ods, Projet_juil.07_0934.xls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]
2024-10-21 removing PCB bckup tracking
2025-08-21 updating PCB Kicad v9
    [1985250.stp, CUI_DEVICES_TS07-667-30-BK-100-SMT-TR.step, Coilcraft-MSS1048.STEP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]
2025-08-21 Correcting PCB bug J3 pin 7 at GND
    [tank_PCB.kicad_pcb, tank_PCB.kicad_sch]
2025-08-22 WIP adsdriver callback errors + NVS value error
    [main.cpp]
2025-08-24 Correction default pFactor
    [2024-06-29 Comput.ods]
2025-08-25 Pressure Cluster error handle writing persistent value
    [main.cpp]
2025-08-31 issuing JLPCB gerber files
    [tank_PCB-B_Cu.gbl, tank_PCB-B_Mask.gbs, tank_PCB-B_Paste.gbp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]
2025-09-01 Working on enclosure
    [zTank_enclosure.FCStd]
2025-09-01 deleting gitignore in PCB folder
2025-09-11 Finalizing enclosure design and Readme
    [Inserts.ods, zTank_enclosure-Button.stl, zTank_enclosure-Enclosure_Top.3mf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]
2025-09-11 WIP on readme PCB
2025-10-04 Clearing Kicad Warnings
    [1985250.stp, CUI_DEVICES_TS07-667-30-BK-100-SMT-TR.step, Coilcraft-MSS1048.STEP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]
